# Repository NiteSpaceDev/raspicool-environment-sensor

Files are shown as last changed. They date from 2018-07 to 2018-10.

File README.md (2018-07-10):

# Environment sensor module based on the ESP32-Wroom Module

## Overview

This environment sensor is intended to be a low cost sensor that can be deployed throughout the environment controlled by the RaspiCool system.

## Recommended sensor locations
* One sensor for each room
  * Thermostat includes a sensor and only needs a sensor module if drafts, etc. make the built-in sensor unreliable.
* One sensor for each return air vent
* One sensor in the vent closest to the AC coil
  * This sensor, combined with the return air sensors, is used to track 'delta-t', which can help indicate system troubles.

## Hardware description
The sensor module is built using an esp32-wroom module, providing encryption, wifi, and bluetooth capabilities.  The primary sensor included is the BME280, providing temperature, humidity, and pressure data.   Power is provided by an 18650 battery.

## Sensor Options
* Option to include SSD1306 oled display
* SPI and I2C expansion points included on sensor pcb

# Usage
## Sensor pairing
The base sensor image does not include any wifi configuration or authentication certificates.   When the sensor is powered in this state, it will scan bluetooth looking for a RaspiCool thermostat.   When it finds one, it will trigger a popup on the thermostat to confirm pairing the sensor.

* Note:   The thermostat must be set into pairing mode in order to pair additional sensors.  Bluetooth is normally off on the thermostat.

Pairing causes the following events:
- Wifi configuration is sent via bluetooth to the sensor
- Thermostat will assign a static IP and set a static DHCP reservation for the sensor
- Sensor receives IP via DHCP and verifies the address with the thermostat registration service
- Client authentication certificates are generated and delivered to the sensor
- Sensor retrieves additional configuration from the thermostat services
- Sensor resets and starts normal data loop

## Sensor operation
In normal operation, the sensor spends the majority of the time in a sleep state.  During each wake cycle, the following events happen:
* Read sensor values
* Cache current value
* Determine if values need to be reported - Enter sleep at this point if no reporting needed
  * Sensor values have changed by more than threshhold (Default 0.1c, 0.5%) 
  * Reporting cycle time has expired (Default 1 minute)
* Bring wifi online
* Connect to thermostat
* Send sensor data
* Check for commands (Update, config, etc.)
* Enter sleep

TODO:   Thermostat data via https api instead of mqtt?

## How to install this app

- mos build
- mos flash

## Helpful commands
- See bashaliases.sh for information

# Built for (MongooseOS)[https://mongoose-os.com]

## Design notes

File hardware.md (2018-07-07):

# Control chip info
The reference environment sensor is built on the ESP32 chip.  For ease of use, the ESP32-Wroom module is used, integrating SPI flash and antenna into a small module with castelated pins for soldering.

# Available power
The sensor module is powered using an 18650 battery.   The voltage regulator provides a maximum of 600ma of current.  The board uses approximately 250ma while active, leaving approximately 300ma available for expansion.

# SPI Bus info
### GP SPI0 - Master
|SPI Pin|GPIO PIN|Wroom Hardware Pin|Description|Board Location|
|---|---|---|---|---|
|clk| 27 | 12 | SPI bus clock | |
|MOSI| 26 | 11 | Data from master to slave | |
|MISO| 25 | 10 | Data from slave to master | |
|SSA| 14 | 13 | Slave select A: Open | J5 |
|SSB| 12 | 14 | Slave select B: Open | J6 |
|SSC| 33 | 9 | Slave select C: Open | J7 |

### Wroom 4M Parallel QSPI Flash on GPIO pins 6-11
|SPI Pin|GPIO PIN|Wroom Hardware Pin|Description|
|---|---|---|---|
|clk| 6 | 20 | SPI bus clock |
|MOSI| 8 | 22 | Data from master to slave |
|MISO| 7 | 21 | Data from slave to master |
|SHD / SD2 | 9 | 17 | /HOLD |
|SWP / SD3 | 10 | HW18 | /WP |
|SCS / CMD | 11 | HW19 | /CS |

# I2C Bus info
## Pin mapping to WROOM
|I2C Pin|GPIO PIN|Wroom Hardware Pin|Board Location|
|---|---|---|---|
|CLK| 16 | 27 ||
|Data| 17 | 28 ||
|enable1| 18 | 30 | J3 |
|enable2| 19 | 31 | J4 |

## Addresses:
|Address|Device|
|---|---|
|0x76|BME280 Sensor|
|0x78|OLED (Optional, connect to J3 or J4 )|

# Connector Pinouts
## SPI expansion
|Pin|Name|
|---|----|
|1|VCC - 3.3v|
|2|Clock|
|3|MOSI|
|4|MISO|
|5|slave select|
|6|Ground|

SPI Expansion headers are located at J5, J6, and J7

## I2C expansion
|Pin|Name|
|---|----|
|1|VCC - 3.3v|
|2|Clock|
|3|Data|
|4|Ground|

I2C expansion headers are located at J1, J2, J3, and J4.   VCC for J3 and J4 is controlled by using GPIO pins 18 and 19.

## JTAG
JTAG header on the board is setup for [Digilent HS2 JTAG adapter](https://store.digilentinc.com/jtag-hs2-programming-cable/) and located at J8

|Pin|Name|
|---|----|
|1|mtms|
|2|mtdi|
|3|mtdo|
|4|clock|
|5|Ground|
|6|VCC - 3.3v|

# Bill of Materials - Board version 1.0
|Reference|Value|Description|Datasheet|
|---|-----|---|---|
|U1|AP2112K-3.3TRG1|3.3v 600ma voltage regulator|(https://www.diodes.com/assets/Datasheets/AP2112.pdf)
|U2|ESP32-WROOM|ESP32 Wroom integrated module|(https://www.espressif.com/sites/default/files/documentation/esp32-wroom-32_datasheet_en.pdf)
|U3|BME280|Bosch BME280 Temperature/Humidity/Pressure sensor|(https://ae-bst.resource.bosch.com/media/_tech/media/datasheets/BST-BME280_DS001-12.pdf)
|C1|1uF|SMD1206 Capacitor||
|C2|10uF|SMD1206 Capacitor||
|C3|1uF|SMD1206 Capacitor||
|C4|100nF|SMD1206 Capacitor||
|C5|10uF|SMD1206 Capacitor||
|C6|100nF|SMD1206 Capacitor||
|C7|100nF|SMD1206 Capacitor||
|C8|100nF|SMD1206 Capacitor||
|R1|10k|SMD1206 Resistor||
|R2|3.3k|SMD1206 Resistor||
|R3|10k|SMD1206 Resistor||
|R4|4.7k|SMD1206 Resistor||
|R5|4.7k|SMD1206 Resistor||
|R6|100|SMD1206 Resistor||
|R7|100|SMD1206 Resistor||
|R8|100|SMD1206 Resistor||
|R9|100|SMD1206 Resistor||
|D1|1N5819|SMD1206 (SOD123) Diode||
|BT1|18650 Battery holder|SMD 18650 Battery holder|(https://www.aliexpress.com/item/10pcs-DIY-Battery-Holder-SMT-2pin-for-single-18650-rechargeable-Lithium-battery-SMD-Surface-Mount-PCB/32734996935.html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)|
|JP1|2 Pin Header|Optional - programming||
|J1|4 Pin Header|Optional - I2C||
|J2|4 Pin Header|Optional - I2C||
|J3|4 Pin Header|Optional - I2C||
|J4|4 Pin Header|Optional - I2C||
|J5|6 Pin Header|Optional - SPI||
|J6|6 Pin Header|Optional - SPI||
|J7|6 Pin Header|Optional - SPI||
|J8|6 Pin Header|Optional - JTAG||

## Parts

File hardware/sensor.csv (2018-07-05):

Id | Designator | Package | Quantity | Designation | Supplier and ref
1 | R7,R6,R8,R9 | R_1206 | 4 | 100
2 | BT1 | Keystone_1042_1x18650 | 1 | Battery
3 | U1 | SOT95P285X140-5N | 1 | AP2112K-3.3TRG1
4 | U2 | ESP32-WROOM | 1 | ESP32-WROOM
5 | U3 | Bosch_LGA-8_2.5x2.5mm_Pitch0.65mm_ClockwisePinNumbering | 1 | BME280
6 | C1,C3 | C_1206 | 2 | 1uF
7 | C2,C5 | C_1206 | 2 | 10uF
8 | C4,C6,C9 | C_1206 | 3 | 0.1uF
9 | C7,C8 | C_1206 | 2 | 100nF
10 | D1 | D_1206 | 1 | 1N5819
11 | R1,R3 | R_1206 | 2 | 10k
12 | R2 | R_1206 | 1 | 3.3k
13 | R4,R5 | R_1206 | 2 | 4.7k
14 | J1,J2,J3,J4 | Pin_Header_Straight_1x04_Pitch2.54mm | 4 | Conn_01x04
15 | J5,J6,J7,J8 | Pin_Header_Straight_1x06_Pitch2.54mm | 4 | Conn_01x06
16 | JP1 | Pin_Header_Straight_1x02_Pitch2.54mm | 1 | Jumper_NO_Small
17 | REF*** | KiCad-Logo2_12mm_SilkScreen | 1 | KiCad-Logo2_12mm_SilkScreen

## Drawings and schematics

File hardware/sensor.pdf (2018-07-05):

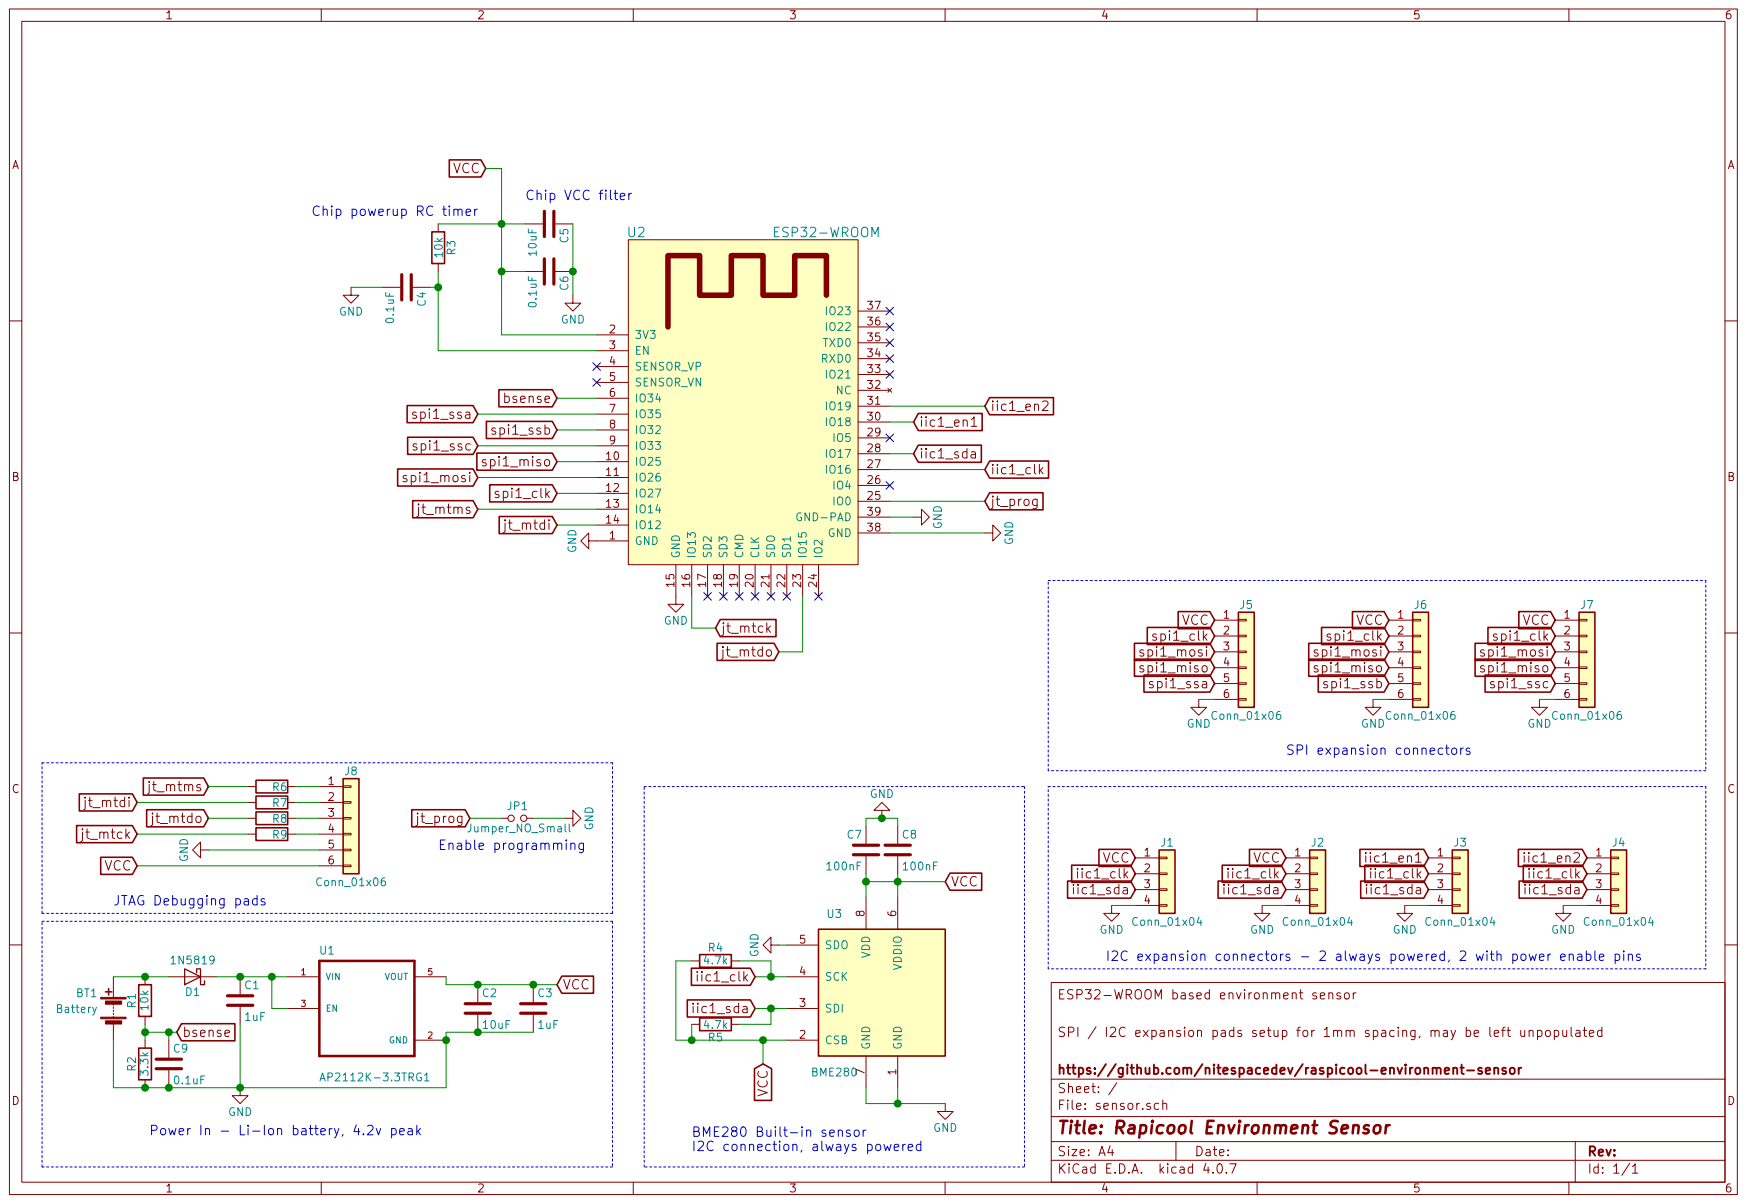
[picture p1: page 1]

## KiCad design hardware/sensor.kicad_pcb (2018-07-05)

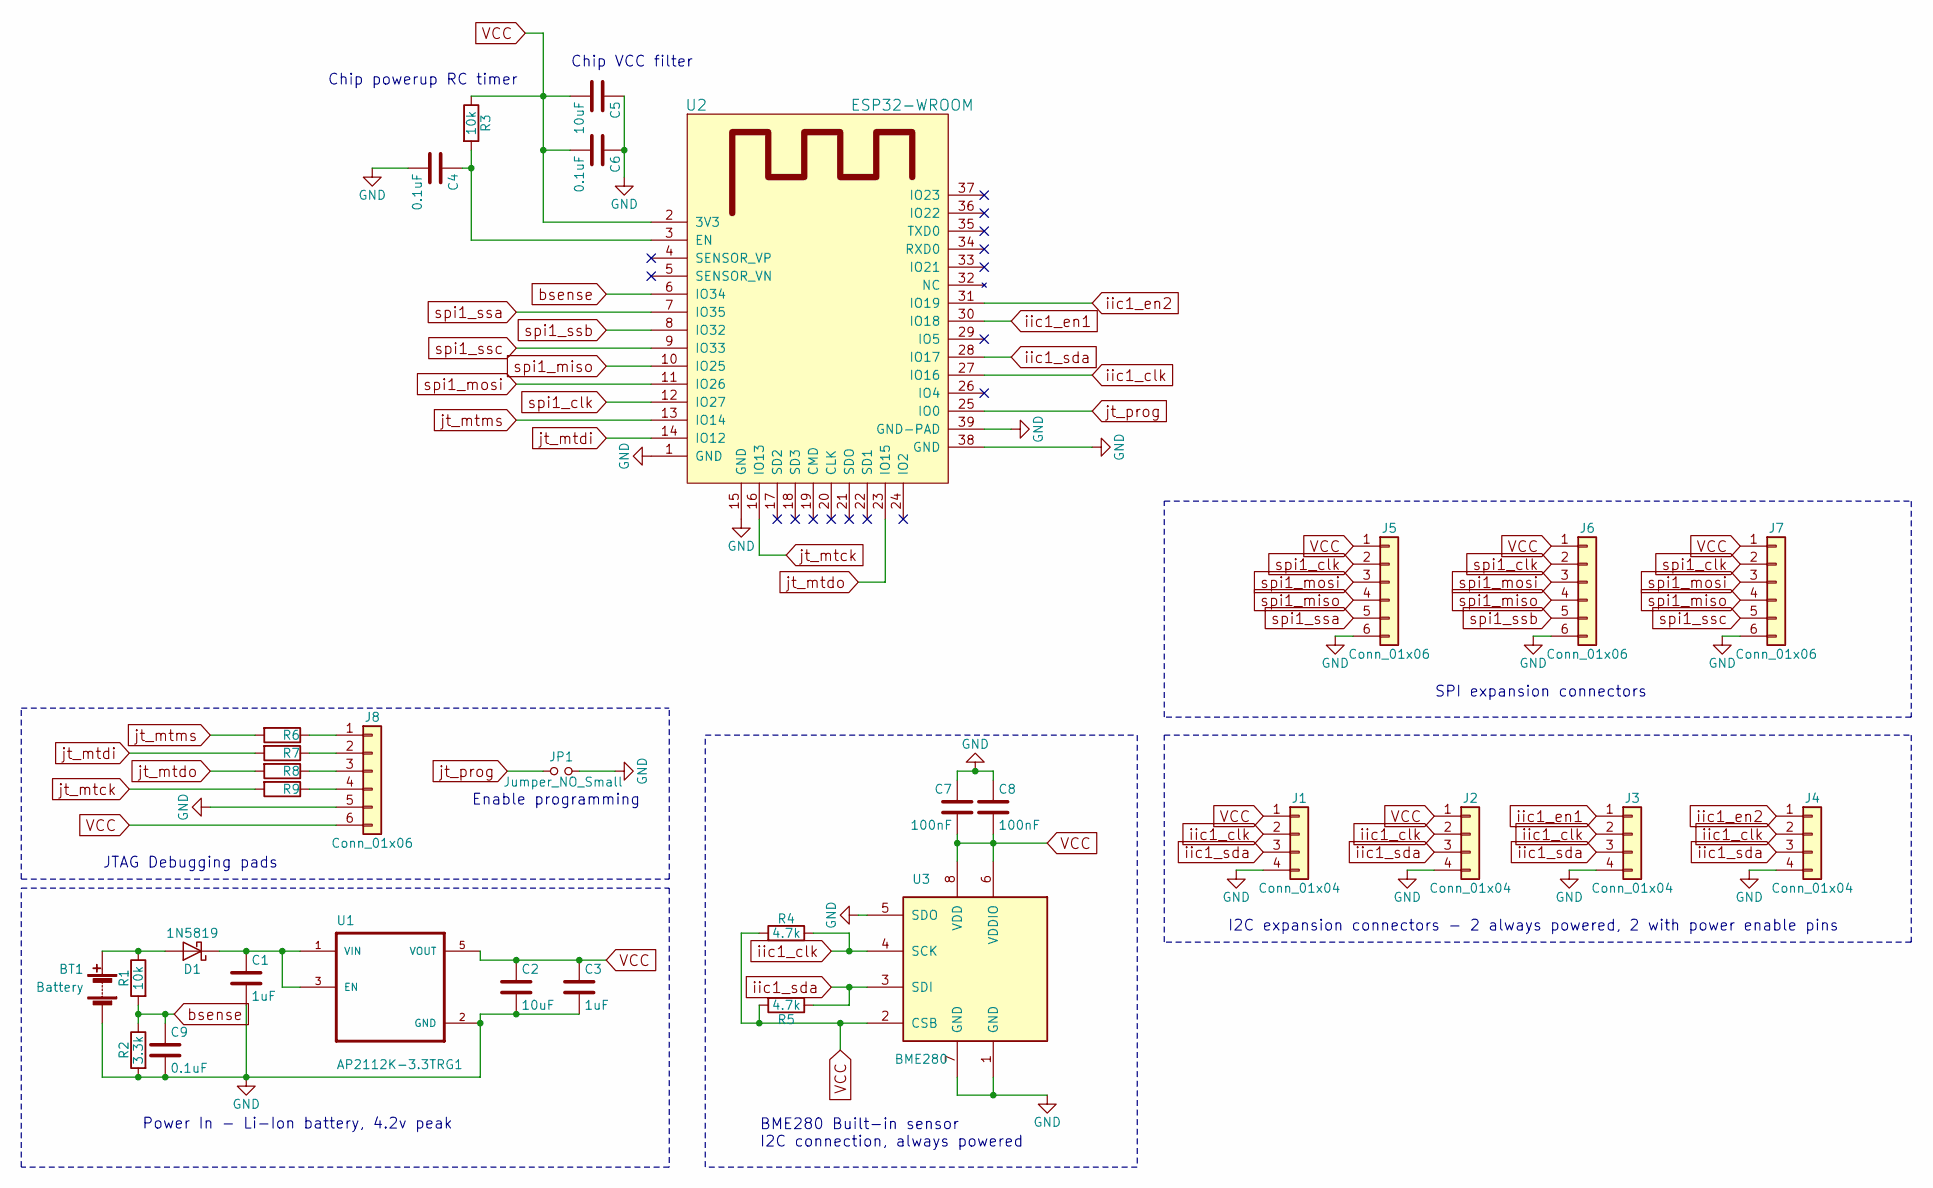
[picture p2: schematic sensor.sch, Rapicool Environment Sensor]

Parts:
BT1: Battery; Keystone_1042_1x18650
C1, C3: 1uF; C_1206
C2, C5: 10uF; C_1206
C4, C6, C9: 0.1uF; C_1206
C7, C8: 100nF; C_1206
D1: 1N5819; D_1206
J1, J2, J3, J4: Conn_01x04; Pin_Header_Straight_1x04_Pitch2.54mm
J5, J6, J7, J8: Conn_01x06; Pin_Header_Straight_1x06_Pitch2.54mm
JP1: Jumper_NO_Small; Pin_Header_Straight_1x02_Pitch2.54mm
R1, R3: 10k; R_1206
R2: 3.3k; R_1206
R4, R5: 4.7k; R_1206
R6, R7, R8, R9: 100; R_1206
U1: AP2112K-3.3TRG1; SOT95P285X140-5N
U2: ESP32-WROOM
U3: BME280; Bosch_LGA-8_2.5x2.5mm_Pitch0.65mm_ClockwisePinNumbering

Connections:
GND: BT1.2 (-), C1.2, C2.2, C3.2, C4.2, C5.1, C6.1, C7.1, C8.1, C9.2, J1.4, J2.4, J3.4, J4.4, J5.6, J6.6, J7.6, J8.5, JP1.2, R2.2, U1.2 (GND), U2.1 (GND), U2.15 (GND), U2.38 (GND), U2.39 (GND-PAD), U3.1 (GND), U3.5 (SDO), U3.7 (GND)
unnamed: BT1.1 (+), D1.2 (A), R1.1
unnamed: C1.1, D1.1 (K), U1.1 (VIN), U1.3 (EN)
unnamed: C4.1, R3.2, U2.3 (EN)
unnamed: J8.1, R6.1
unnamed: J8.2, R7.1
unnamed: J8.3, R8.1
unnamed: J8.4, R9.1
VCC: C2.1, C3.1, C5.2, C6.2, C7.2, C8.2, J1.1, J2.1, J5.1, J6.1, J7.1, J8.6, R3.1, R4.2, R5.2, U1.5 (VOUT), U2.2 (3V3), U3.2 (CSB), U3.6 (VDDIO), U3.8 (VDD)
bsense: C9.1, R1.2, R2.1, U2.6 (IO34)
iic1_clk: J1.2, J2.2, J3.2, J4.2, R4.1, U2.27 (IO16), U3.4 (SCK)
iic1_en1: J3.1, U2.30 (IO18)
iic1_en2: J4.1, U2.31 (IO19)
iic1_sda: J1.3, J2.3, J3.3, J4.3, R5.1, U2.28 (IO17), U3.3 (SDI)
jt_mtck: R9.2, U2.16 (IO13)
jt_mtdi: R7.2, U2.14 (IO12)
jt_mtdo: R8.2, U2.23 (IO15)
jt_mtms: R6.2, U2.13 (IO14)
jt_prog: JP1.1, U2.25 (IO0)
spi1_clk: J5.2, J6.2, J7.2, U2.12 (IO27)
spi1_miso: J5.4, J6.4, J7.4, U2.10 (IO25)
spi1_mosi: J5.3, J6.3, J7.3, U2.11 (IO26)
spi1_ssa: J5.5, U2.7 (IO35)
spi1_ssb: J6.5, U2.8 (IO32)
spi1_ssc: J7.5, U2.9 (IO33)

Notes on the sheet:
Power In - Li-Ion battery, 4.2v peak
BME280 Built-in sensor I2C connection, always powered
I2C expansion connectors - 2 always powered, 2 with power enable pins
SPI expansion connectors
Enable programming
JTAG Debugging pads
Chip VCC filter
Chip powerup RC timer

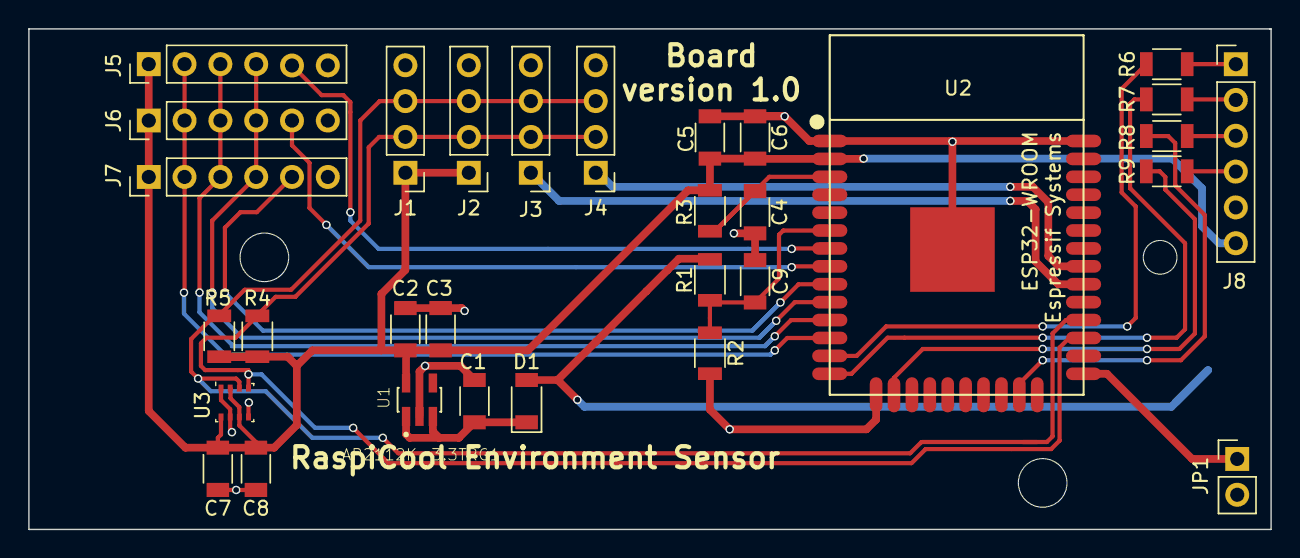
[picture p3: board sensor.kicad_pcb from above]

Board: 2 copper layers, 88.1 x 35.5 mm, 32 parts (1 on the bottom side), 25 nets.

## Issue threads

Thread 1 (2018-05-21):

OLED Display

nitehawk, 2018-05-21:
- [ ] Current data
- [ ] Button push to switch between C & F?
- [ ] Battery %

nitehawk, 2018-07-29:
Currently battery % is in the form of current battery voltage.  This eventually needs to be mapped into charge %.

Using mgos_adc_read_voltage seems to have a side effect of reporting 0.142 volts with no battery present, but this is not relevant to production usage.

Need to experiment with lower voltage batteries to confirm that reading is accurate

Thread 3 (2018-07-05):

Hardware enhancements

nitehawk, 2018-07-05:
Potential enhancements:
* One or two buttons for basic interface
* LED to show status - flash during reporting cycle - Option to disable
  * Tricolor to allow showing if there are errors, or unconfigured, etc.

nitehawk, 2018-07-10:
Split I2C bus:   All devices on an i2c bus should be getting vcc together.   Switchable i2c devices could be useful, but a dedicated bus is needed.

nitehawk, 2018-07-29:
* Adjust traces to maximize reflow success rate (center of pads vs edges that will pull small parts off position)
* Thermal vias on central GND pad of wroom module
* Potentially update to 4-layer board w/ VCC & GND planes -

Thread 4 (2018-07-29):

Sensor reset code

nitehawk, 2018-07-29:
We need a mechanism to factory reset a sensor.

[ ] Remove user layer config files (including wifi)
[ ] Reset boot code to use factory image?

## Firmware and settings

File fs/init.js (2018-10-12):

load('api_config.js');
load('api_rpc.js');
load('api_gpio.js');
load('api_timer.js');
load('api_mqtt.js');
load('api_sensor_utils.js');
load('api_ssd1306.js');
load('api_bme280.js');
load('api_adc.js');

// Who are we
let sensorname = Cfg.get('sensor.name');

// Battery on pin 34
let battery = 34;
ADC.enable(battery);

print("Initializing");

let OurADC = {
readv: ffi('int mgos_adc_read_voltage(int)'), };

// On the ESP32 dev board we are using, GPIO pin 16 is connected to the OLED
//  RST pin.   We pull this pin high to power the OLED
// TODO - Make this a config element
//GPIO.set_mode(18, GPIO.MODE_OUTPUT)
//GPIO.write(18, 1);
//GPIO.set_mode(16, GPIO.MODE_OUTPUT)
//GPIO.write(16, 1);

// Turn on BMP / BME 280 sensor
let sensor = BME280.createI2C(118);

let oled = SSD1306.get_oled();
oled.refresh();

// Start a 5 second refresh loop (15 second "final" refresh?)
Timer.set(15000, true, function() {
		// Read the sensor data
		let reading={
			"sensor": sensorname,
			"vadc": ADC.read(battery),
			"vadcv": OurADC.readv(battery),
			"pressure": SensorUtils.atmospheresHg(sensor.readPress()),
			"temp": sensor.readTemp(),
			"humidity": Math.round(sensor.readHumid())
		};
	  let tf = Math.round(SensorUtils.fahrenheit(reading.temp));

		// Get battery voltage - 6800 / 2200 divider, adc ref 1.1
		//
		//reading.voltage = (reading.vadc/4095)*1.1*(10000/3300);
		//reading.voltage = (reading.vadc/4095)*2*3.3*1.1;
		reading.voltage = ((reading.vadcv/1000)*(10000+3300))/3300;

		// Update the OLED Display
		oled.clearDisplay();
		oled.drawStrColor(2, 11, "Temp (c): " + JSON.stringify(reading.temp),1,0);
		oled.drawStrColor(2, 21, "Temp (f): " + JSON.stringify(tf),1,0);
		oled.drawStrColor(2, 31, "Pressure: " + JSON.stringify(reading.pressure),1,0);
		oled.drawStrColor(2, 41, "Humidity: " + JSON.stringify(reading.humidity) + "%",1,0);
		oled.drawStrColor(2, 51, "Battery: " + JSON.stringify(reading.voltage),1,0);
		oled.refresh();

		// Publish current data via mqtt
		let res = MQTT.pub('environment/data', JSON.stringify(reading),0);

		// Print output to console.
		print(JSON.stringify(reading));
	}, null);

// RPC handlers for sensors
RPC.addHandler('Temp.Read', function(args) {
	  return { value: sensor.readTemp() };
	});

RPC.addHandler('Humid.Read', function(args) {
	  return { value: sensor.readHumid() };
	});

RPC.addHandler('Press.Read', function(args) {
	  return { value: sensor.readPress() };
	});

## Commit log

2018-05-21 Add Humidity call
    Fix default pin to IO-5
    [init.js]
2018-05-21 Make an app setting for the sensor type too
2018-05-22 Use GPIO pin 2 by default
    This will get sorted out in a stable fashion once the design is taken off breadboard and put to hardware.
2018-05-24 Working super basic version of OLED support
    This has a ton of cleanup still needed, but it does bring the OLED online for the new ESP32 board being tested
    Next up is some additional testing to confirm if we actually need pin16 high and a ton of cleanup. Part of the cleanup should include sticking the OLED code into different modules and choosing what w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
    Note - The code base will be targeted towards specific hardware configs, but we want to keep some open source flexibility in the design
2018-05-26 Working BME280 sensor code
    BME 280 sensor working except for humidity, Code cleanup and refactor due next.
2018-05-27 Some minor cleanups, extend display code
    Display is updated to output temp in both C & F, plus pressure & humidity
2018-05-30 Restructure sensor data collection
    Collect sensor data directly into JSON data structure. Slow collection pace, start attempting to collect battery data. Publish sensor data to MQTT.
2018-06-09 Some of the SSD1306 calls seem to have changed
    Fixup some of the FFI prototypes
2018-06-09 Updates to MQTT pushes
    * Start building deeper application config
    * Pull sensor name from config
    * Continue attempts to get usable data from ADC
2018-06-26 Add I2C info on BME280 sensor
2018-07-01 mosbuild function will always build esp32
2018-07-01 Start building hardware schematics
    Building in KiCad
    [sensor.kicad_pcb, sensor.sch]
2018-07-02 Continue schematic work
    Cleanup power
    Add I2C connectors
    Connect BME280 w/ I2C
    [power.sch, sensor.kicad_pcb, sensor.sch]
2018-07-03 Continue HW design
    * Setup SPI expansion connectors
    * Re-annotate caps for power regulator and WROOM power
    * Add globals for JTAG pins
    * Rough grouping of parts on PCB
    - Note - still need to make battery setup choices and footprint choices for passives
    [sensor.kicad_pcb, sensor.sch]
2018-07-03 Hierarchy doesn't make sense
    This is already gone from the schematic - hierarchy doesn't make sense for this module
    [power.sch]
2018-07-04 Sensor board v1 schematic done
    * JTAG added
    * Keep latest schematic in PDF for easy viewing
    * Attempt to fix markdown on hardware description
    [sensor.sch]
2018-07-04 Additional tweaks
    Update footprints for SPI & I2C expansion
    Set resistor values for battery voltage divider
    Series resistors for JTAG
    [sensor.sch]
2018-07-05 Additional fixes, Place & route board
    * Add junction on C9 to GND
    * Swap SPI pins for cleaner routing
    * Finish initial routing of board
    TODO: Finish silkscreen layout
    * Reference labels
    * Page labels
    * Board version markings
    * Art
    [sensor.kicad_pcb, sensor.sch]
2018-07-05 V1.0 board done
    * Refs updated
    * version info added
    Note - For now, we're leaving the gerber output directory out of the github project
    Sensor.csv is early BOM
    TODO:
    * Update hardware markdown with new pin info, including board references
    [sensor.csv, sensor.kicad_pcb]
2018-07-07 Update hardware description
    * Add BOM
    * Update pin assignments for SPI
    * Add description for SPI / I2C expansion headers
    * Remove esp8266 config
2018-07-10 Describe sensor design
2018-07-29 Hardware V1 code functional
    Some minor migrations to get this code functional with the V1 sensor hardware config. Test build w/ programmer and breadboard with hardware pinout.
